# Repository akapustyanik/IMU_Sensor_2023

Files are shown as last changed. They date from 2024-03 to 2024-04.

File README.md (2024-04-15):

# IMU_Sensor_2023


  Данный модуль позволит постоянно опрашивать микросхему гироскопа независимо от работы основного алгоритма на основном микроконтроллере, такая система обезопасит от потери выходных данных с датчика и позволит лучше фильтровать данные. Передача данных на основной микроконтроллер может выполняться по любому запрограммированному протоколу, что является большим преимуществом, поскольку можно написать проверку полученных данных и обезопасить алгоритм на основном микроконтроллере от неправильных значений датчика.

  Для инерциального модуля собственной разработки была выбрана распространённая микросхема гироскопа-акселерометра MPU6050. Для данного датчика есть готовое и отлаженное ПО в открытом доступе, что сокращает время на отладку инерционного модуля. Распространённым аналогом MPU6050 можно выделить MPU9250. Если сравнить датчики, то можно выделить, что MPU6050 дешевле и доступнее, но проигрывает меньшей точностью и отсутствием магнитометра. Важной частью инерциального модуля собственной разработки является доступность, поэтому был выбран MPU6050.

  В качестве микроконтроллера инерциального модуля собственной разработки был выбран Atmega328P, недорогой, распространённый, доступный микроконтроллер. Вычислительной мощности которого достаточно для выполнения базовых алгоритмов фильтрации данных.

  Популярным аналогом инерциального модуля собственной разработки является модуль гироскопа SparkFun 9DoF Razor IMU M0, представляющий собой готовую платформу с микроконтроллером и микросхемой гироскопа на одной плате. Инерциальный модуль от SparkFun снят с производства, и его покупка не представляется возможной.

  Данный инерциальный модуль был разработан в рамках образовательного проекта MZCAT, с которым можно ознакомиться по ссылке - https://github.com/akapustyanik/MZCAT

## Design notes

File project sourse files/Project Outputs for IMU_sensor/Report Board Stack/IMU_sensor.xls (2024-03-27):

Board Stack Report
Stack Up |  | Layer Stack
Layer | Board Layer Stack | Name | Material | Thickness | Constant
1 |  | Top Paste
2 |  | Top Overlay
3 |  | Top Solder | Solder Resist | 0,010mm | 3,5
4 |  | Top Layer | Copper | 0,036mm
5 |  | Dielectric 2 | PP-006 | 0,071mm | 4,1
6 |  | GND | Copper | 0,035mm
7 |  | Dielectric 1 | FR-4 | 0,320mm | 4,8
8 |  | GND | Copper | 0,035mm
9 |  | Dielectric 3 | PP-006 | 0,071mm | 4,1
10 |  | Bottom Layer | Copper | 0,036mm
11 |  | Bottom Solder | Solder Resist | 0,010mm | 3,5
12 |  | Bottom Overlay
13 |  | Bottom Paste
 | Height : 0,624mm

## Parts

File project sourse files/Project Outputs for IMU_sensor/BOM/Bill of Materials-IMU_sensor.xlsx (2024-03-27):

Comment | Description | Designator | Footprint | LibRef | Quantity
Atmega328P | Atmega328P-MU | DD1 | VQFN32 | Atmega328P | 1
CP2104 |  | DD2 | QFN24-PAD | CP2104 | 1
MPU6050 |  | DD3 | QFN24-PAD | MPU6050 | 1
DW01A | контроллер заряда | DD4 | SOT23-6 | DW01A | 1
TP4056 | линейное зарядное устройство | DD5 | SOP-8 | TP4056 | 1
LM1117GS-5.0 | LM1117GS-5.0 | DD6 | SOT-223 | LM1117 | 1
0,1мк |  | L1 | L0603 | индуктивность | 1
 | Резистор 0,05Вт | R1 | R0402 | Резистор 0.05Вт | 1
1М | Резистор 0,05Вт | R2 | R0402 | Резистор 0.05Вт | 1
520 | Резистор 0,05Вт | R3, R5 | R0402 | Резистор 0.05Вт | 2
5,1к | Резистор 0,05Вт | R4, R6 | R0402 | Резистор 0.05Вт | 2
4,7к | Резистор 0,05Вт | R7 | R0402 | Резистор 0.05Вт | 1
100к | Резистор 0,05Вт | R8 | R0402 | Резистор 0.05Вт | 1
1к | Резистор 0,05Вт | R9, R10, R16 | R0402 | Резистор 0.05Вт | 3
10к | Резистор 0,05Вт | R11, R12, R21 | R0402 | Резистор 0.05Вт | 3
100 | Резистор 0,05Вт | R13, R14, R18, R22, R25, R26, R27, R28, R29 | R0402 | Резистор 0.05Вт | 9
510 | Резистор 0,05Вт | R15, R17, R20 | R0402 | Резистор 0.05Вт | 3
1,2к | Резистор 0,05Вт | R19 | R0402 | Резистор 0.05Вт | 1
100 |  | R23, R24, R30 | R0402x4 | Резисторная сборка 0.05 x 4 | 3
360 | Резистор 0,05Вт | R31 | R0402 | Резистор 0.05Вт | 1
 |  | SW1 | it-1187 | button | 1
 | Запаиваемая перемычка | SW2 | Jumper_0.5x1 | Jumper | 1
 |  | SW3 | MK12C02 | switch | 1
 | smd led | VD1, VD2, VD4, VD5, VD6 | 0603 - led | smd_led | 5
 | Диод Шоттки | VD3 | SOD123_A | DiodeSchottky | 1
SK6812 | светодиод с пиксельной адресацией SK6812 4020 | VD7 | 3535 | SK6812 | 1
FS8205A | мофсфет | VT1 | TSSOP-8 | FS8205A | 1
IRLML2244TRPBF | мосфет n-канал IRLML2244TRPBF | VT2 | SOT23 | IRLML2244TRPBF | 1
USB Type-C | USB Type-C USB4105-GF-A / GCT | X1 | USB4105-15-A-120 | USB4105 | 1
53048-0210 | Разъем - 3 конт. розетка | X2 | 53048-0210 | Header_2 | 1
MW-2MR | Разъем - 3 конт. розетка | X3 | MW-2MR | Header_2 | 1
PLS 1 x 9 |  | X4, X5 | PLS2-9 - emty | PLS 1 x 9 | 2
 |  | X6 | PLS2-6 - emty | PLS 1 x 6 | 1
16Мгц | 12.88605 / Geyer | XT1 | KX-7 | Резонатор | 1
0,1мк |  | С1, С2, С3, С4, С9, С13, С15, С16, С23 | C0402 | Кер. конденсатор | 9
0,1мк |  | С5 | C0603 | Кер. конденсатор | 1
22 |  | С6, С7 | C0402 | Кер. конденсатор | 2
1мк |  | С8, С12 | C0402 | Кер. конденсатор | 2
4,7мк |  | С10 | C0603 | Кер. конденсатор | 1
0,01мк |  | С11, С14 | C0402 | Кер. конденсатор | 2
0,022мк |  | С17 | C0402 | Кер. конденсатор | 1
10мк |  | С18, С19, С20, С21, С22 | C0603 | Кер. конденсатор | 5

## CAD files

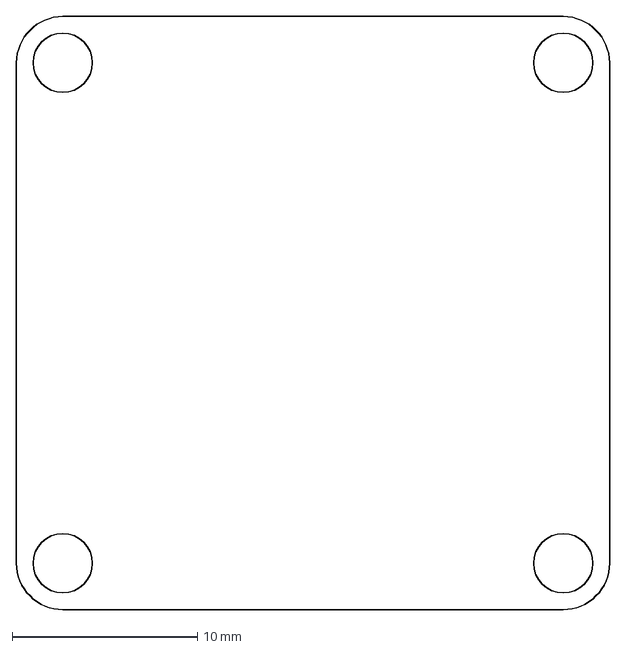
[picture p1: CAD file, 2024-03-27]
project sourse files/IMU_loop.dxf
32.0 x 32.0 mm

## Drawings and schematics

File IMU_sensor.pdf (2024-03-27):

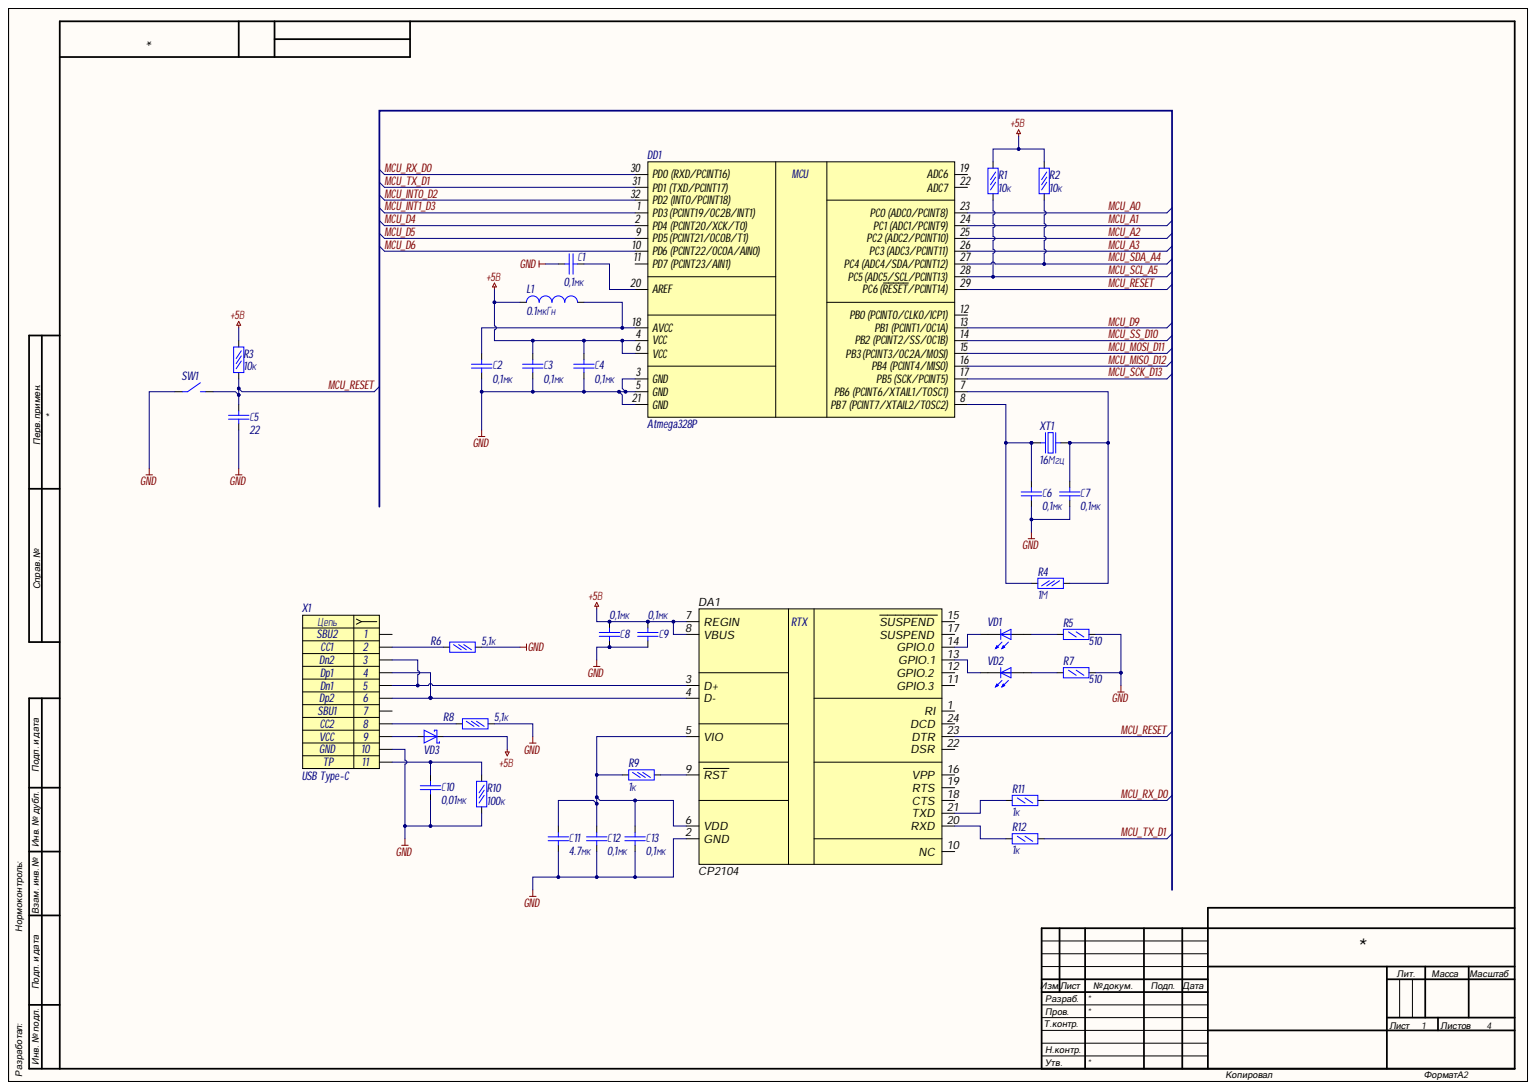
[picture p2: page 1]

MCU_D4 | PD4 (PCINT20/XCK/T0) 2 | MCU_A1
MCU_D5 | PD5(PCINT21/OC0B/T1) 9 | MCU_A2
MCU_D6 | PD6 (PCINT22/OC0A/AIN0) 10 | MCU_A3

Инв. № подл. Инв. № дубл. Подп. и дата Взам. инв. № Подп. и дата Перв. примен. Справ. №

Цепь
SBU2 | 1
CC1 | 2
Dn2 | 3
Dp1 | 4
Dn1 | 5
Dp2 | 6
SBU1 | 7
CC2 | 8
VCC | 9
GND | 10
TP | 11

REGIN 7 | RTX | GPIO.1
VBUS 8

Лит. | Масса | Масштаб

Изм. | Лист | №докум. | Подп. | Дата
Разраб. | | *
Пров. | | *
Т.контр. | | | | | Лист 1 | Листов 4

Н.контр.
Утв.

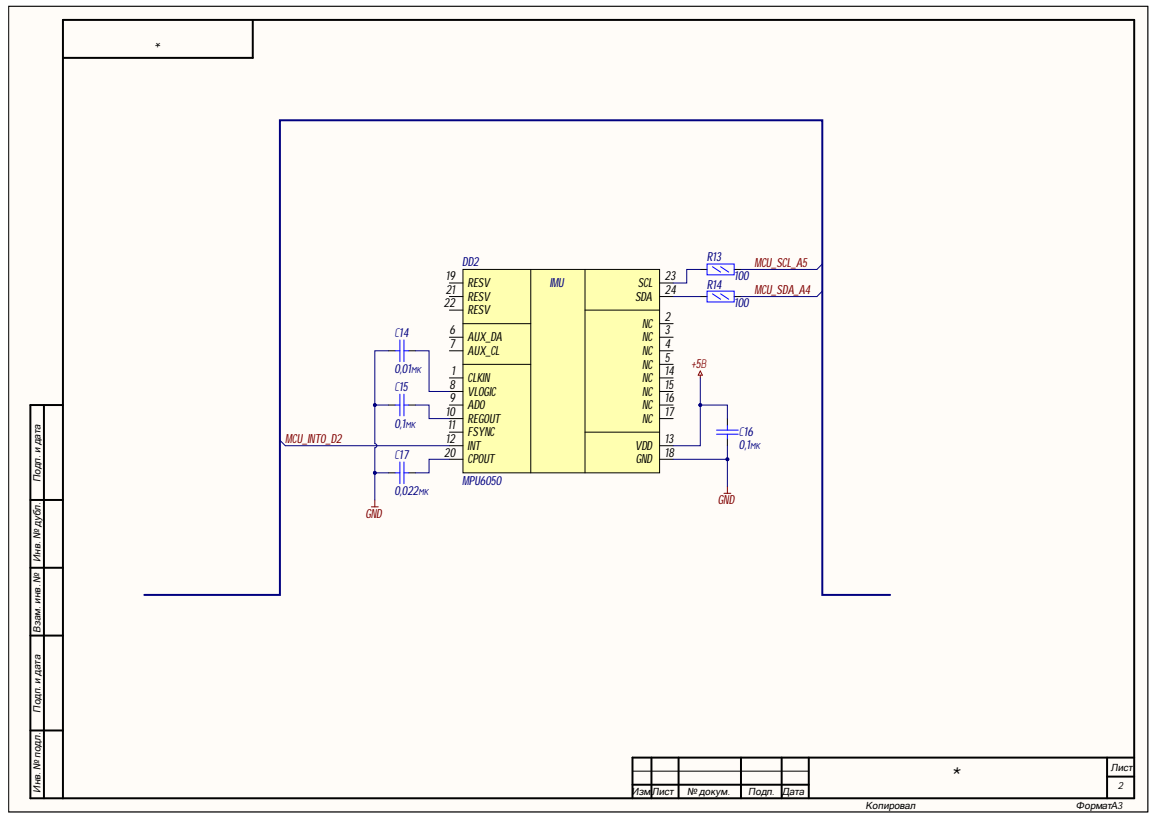
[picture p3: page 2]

DD2 MPU6050 AUX_DA AUX_CL | | 3
RESV 19 | IMU

RESV 22 | | 2 +5В

Инв. № подл. Инв. № дубл. Подп. и дата Взам. инв. № Подп. и дата

Лист 2

Изм | .Лист | № докум . | П одп . | Дата

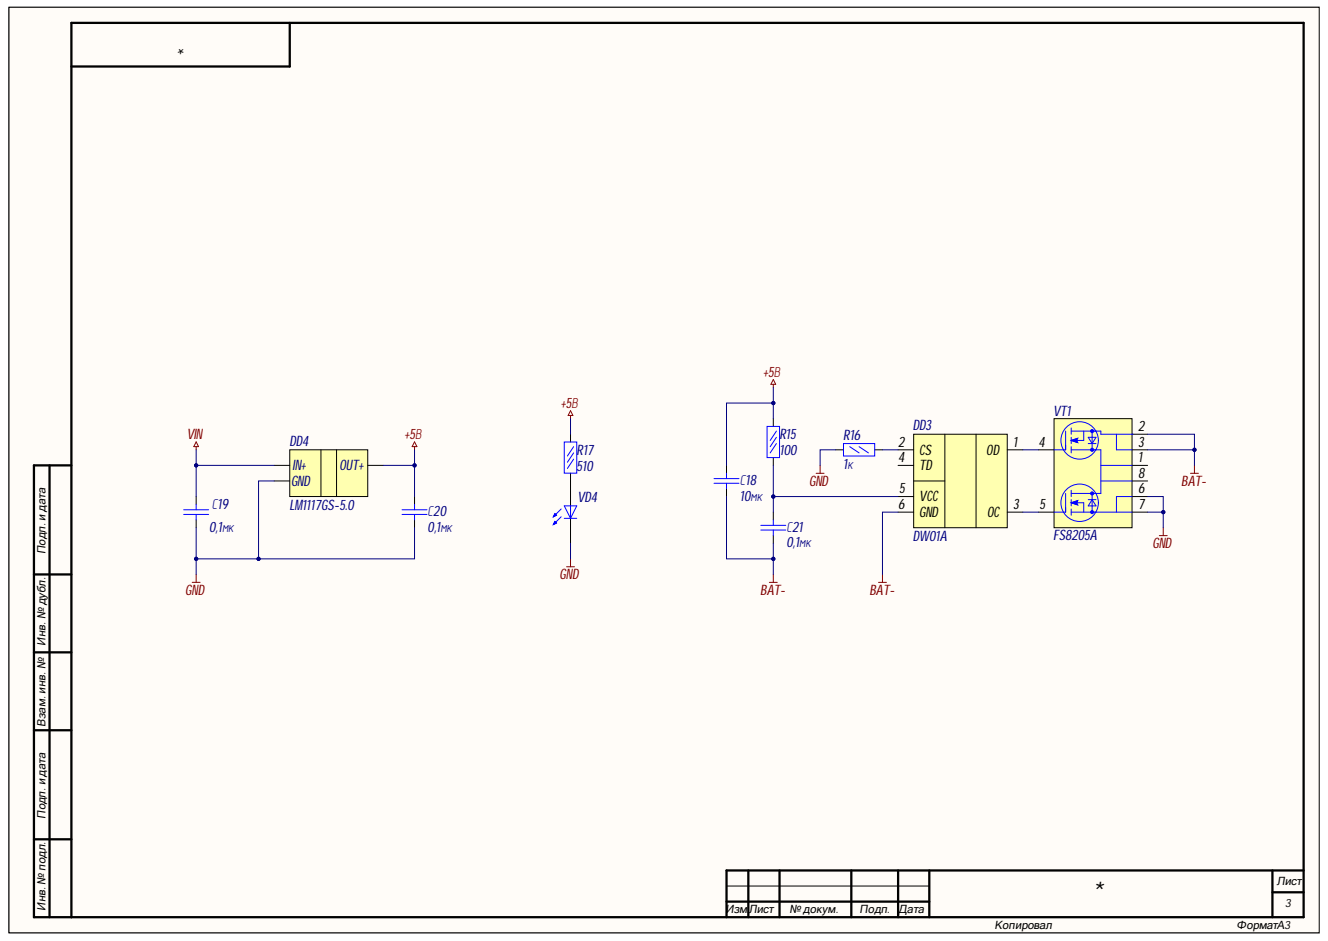
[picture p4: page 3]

Инв. № подл. Инв. № дубл. Подп. и дата Взам. инв. № Подп. и дата

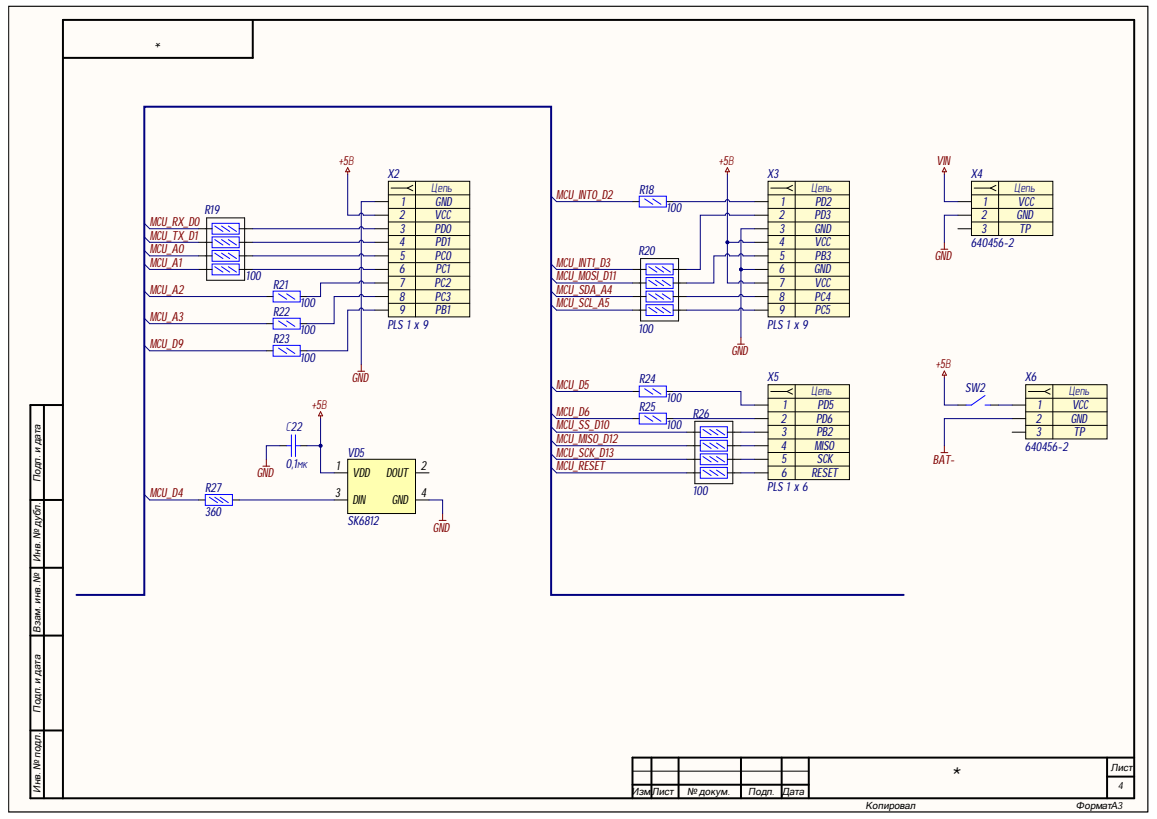
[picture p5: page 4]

Инв. № подл. Инв. № дубл. Подп. и дата Взам. инв. № Подп. и дата

SCK

6 | RESET

Comment | Description | Designator | Footprint | LibRef | Quantity
CP2104 | | DA1 | QFN24-PAD | CP2104 | 1
Atmega328P | Atmega328P-MU | DD1 | | Atmega328P | 1
MPU6050 | | DD2 | | MPU6050 | 1
DW01A | контроллер заряда | DD3 | | DW01A | 1
LM1117GS-5.0 | LM1117GS-5.0 | DD4 | SOT-223 | LM1117 | 1
0.1мкГн | | L1 | SRP1038A | индуктивность | 1
10к | Резистор 0,05Вт | R1, R2, R3 | R0603 | Резистор 0.05Вт | 3
1М | Резистор 0,05Вт | R4 | R0603 | Резистор 0.05Вт | 1
510 | Резистор 0,125Вт | R5, R7 | 0805 | резистор 0.125Вт | 2
5,1к | Резистор 0,05Вт | R6, R8 | R0603 | Резистор 0.05Вт | 2
1к | Резистор 0,05Вт | R9 | R0603 | Резистор 0.05Вт | 1
100к | Резистор 0,05Вт | R10 | R0603 | Резистор 0.05Вт | 1
1к | Резистор 0,125Вт | R11, R12, R16 | 0805 | резистор 0.125Вт | 3
100 | Резистор 0,125Вт | R13, R14, R18, R21, R22, R23, R24, R25 | 0805 | резистор 0.125Вт | 8
100 | Резистор 0,05Вт | R15 | R0603 | Резистор 0.05Вт | 1
510 | Резистор 0,05Вт | R17 | R0603 | Резистор 0.05Вт | 1
100 | | R19, R20, R26 | R0603X4 | Резисторная сборка 0.05 x 4 | 3
360 | Резистор 0,05Вт | R27 | R0603 | Резистор 0.05Вт | 1
| | SW1 | it-1187 | button | 1
| | SW2 | | switch | 1
| smd led | VD1, VD2, VD4 | 0603 - led | smd_led | 3
| Диод Шоттки | VD3 | SOD123_A | DiodeSchottky | 1
SK6812 | светодиод с пиксельной адресацией SK6812 4020 | VD5 | | SK6812 | 1
FS8205A | мофсфет | VT1 | | FS8205A | 1
USB Type-C | USB Type-C USB4105-GF-A / GCT | X1 | USB4105-15-A-120 | USB4105 | 1
PLS 1 x 9 | | X2, X3 | | PLS 1 x 9 | 2
640456-2 | Разъем - 3 конт. розетка | X4, X6 | JST-640456-2 | Header_2 | 2
PLS 1 x 6 | | X5 | | PLS 1 x 6 | 1
16Мгц | 12.88605 / Geyer | XT1 | KX-7 | Резонатор | 1
0,1мк | | С1, С2, С3, С4, С6, С7 | C0402 | Кер. конденсатор | 6
22 | | С5 | C0603 | Кер. конденсатор | 1
0,1мк | | С8, С9, С12, С13, С15, С16, С19, С20, С21, С22 | C0603 | Кер. конденсатор | 10
0,01мк | | С10, С14 | C0603 | Кер. конденсатор | 2
4.7мк | | С11 | C0603 | Кер. конденсатор | 1
0,022мк | | С17 | C0603 | Кер. конденсатор | 1
10мк | | С18 | C0603 | Кер. конденсатор | 1

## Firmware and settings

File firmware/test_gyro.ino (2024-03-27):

#include <config.h>

#include <iarduino_I2C_connect.h>                     // подключаем библиотеку для соединения arduino по шине I2C

#include "LSM6DS3.h"
#include "Adafruit_VL53L0X.h"
#include <Wire.h>

LSM6DS3 myIMU(I2C_MODE, 0x6A);    //I2C device address 0x6A

#define LOX1_ADDRESS 1
#define LOX2_ADDRESS 2
#define LOX3_ADDRESS 3
#define LOX4_ADDRESS 4
#define LOX5_ADDRESS 5

// set the pins to shutdown
#define SHT_LOX1 31 //front
#define SHT_LOX2 30 //left
#define SHT_LOX3 35 //right
#define SHT_LOX4 32 //left_45
#define SHT_LOX5 33 //right_45

#define Rx 15
#define Tx 14


// objects for the vl53l0x
Adafruit_VL53L0X lox1 = Adafruit_VL53L0X();
Adafruit_VL53L0X lox2 = Adafruit_VL53L0X();
Adafruit_VL53L0X lox3 = Adafruit_VL53L0X();
Adafruit_VL53L0X lox4 = Adafruit_VL53L0X();
Adafruit_VL53L0X lox5 = Adafruit_VL53L0X();

// this holds the measurement
VL53L0X_RangingMeasurementData_t measure1;
VL53L0X_RangingMeasurementData_t measure2;
VL53L0X_RangingMeasurementData_t measure3;
VL53L0X_RangingMeasurementData_t measure4;
VL53L0X_RangingMeasurementData_t measure5;

iarduino_I2C_connect I2C2;
struct Str {
  int left;
  int front;
  int right;
  int button1;
  float x;
  float y;
  float z;
};
float startX, startY, startZ;
void setup() {
  Serial.begin(115200);
  Serial3.begin(115200);
  pinMode(47, INPUT);
  setup_sensors();
  if (myIMU.begin() != 0) {
    Serial.println("Device error");
  } else {
    Serial.println("Device OK!");
  }
  delay(3000);
  startX = myIMU.readFloatGyroX();
  startY = myIMU.readFloatGyroY();
  startZ = myIMU.readFloatGyroZ();
}
float ax, ay, az;
float courseX;
float courseY;
float courseZ;
int left_wall;
int front_wall;
int right_wall;

void loop() {
  Str buf;
  read_gyro();
  read_five_sensors();
  buf.left = left_wall;
  buf.front = front_wall;
  buf.right = right_wall;
  buf.button1 = digitalRead(47);
  buf.x = courseX;
  buf.y = courseY;
  buf.z = courseZ;
  Serial3.write((byte*)&buf, sizeof(buf));
  Serial.println(myIMU.readFloatGyroZ());
  //  Serial.print(digitalRead(16));
  //  Serial.print(' ');
  //  Serial.print(digitalRead(17));
  //  Serial.print(' ');
  //  Serial.print(digitalRead(18));
  //  Serial.print(' ');
  //  Serial.println(digitalRead(19));
  //  Serial.println(courseZ);
  delay(1);
}
